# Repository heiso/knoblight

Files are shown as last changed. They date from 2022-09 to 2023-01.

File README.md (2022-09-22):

# KnobLight

Knoblight is a little IoT light knob acting as a dimmer for some homeassistant lights.
Once it's powered, it will connect to a wifi network and discuss with [Home Assistant (https://www.home-assistant.io)](https://www.home-assistant.io/) through [MQTT (https://www.home-assistant.io/integrations/mqtt)](https://www.home-assistant.io/integrations/mqtt/).

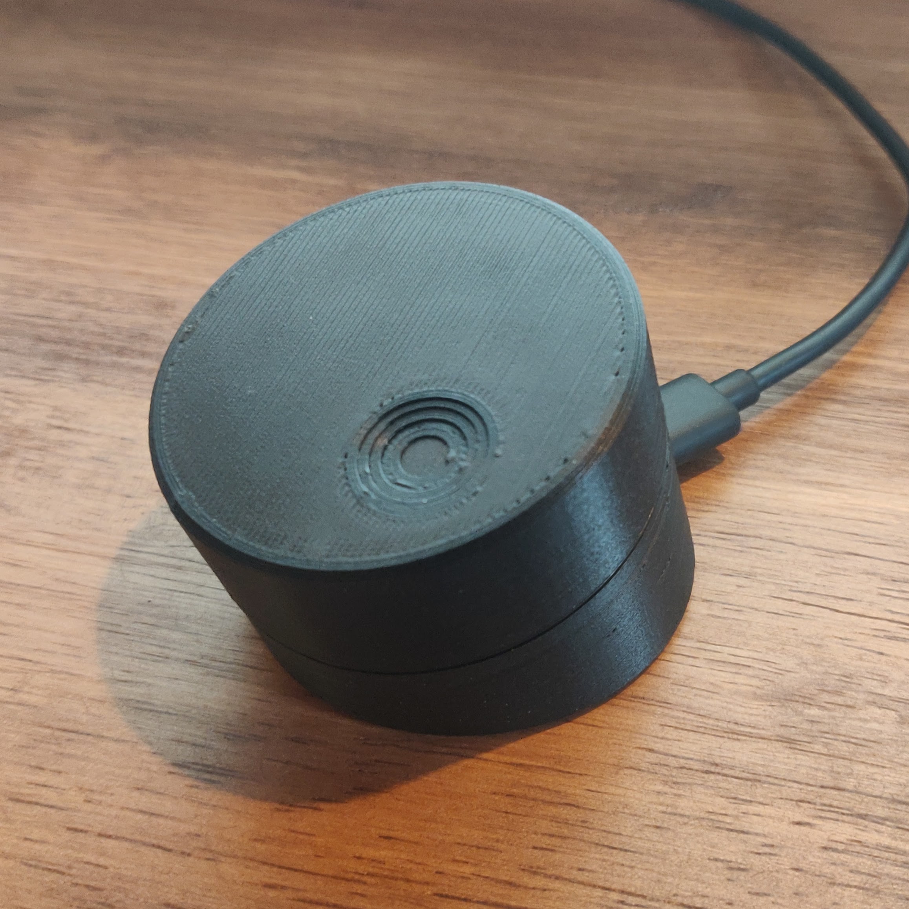
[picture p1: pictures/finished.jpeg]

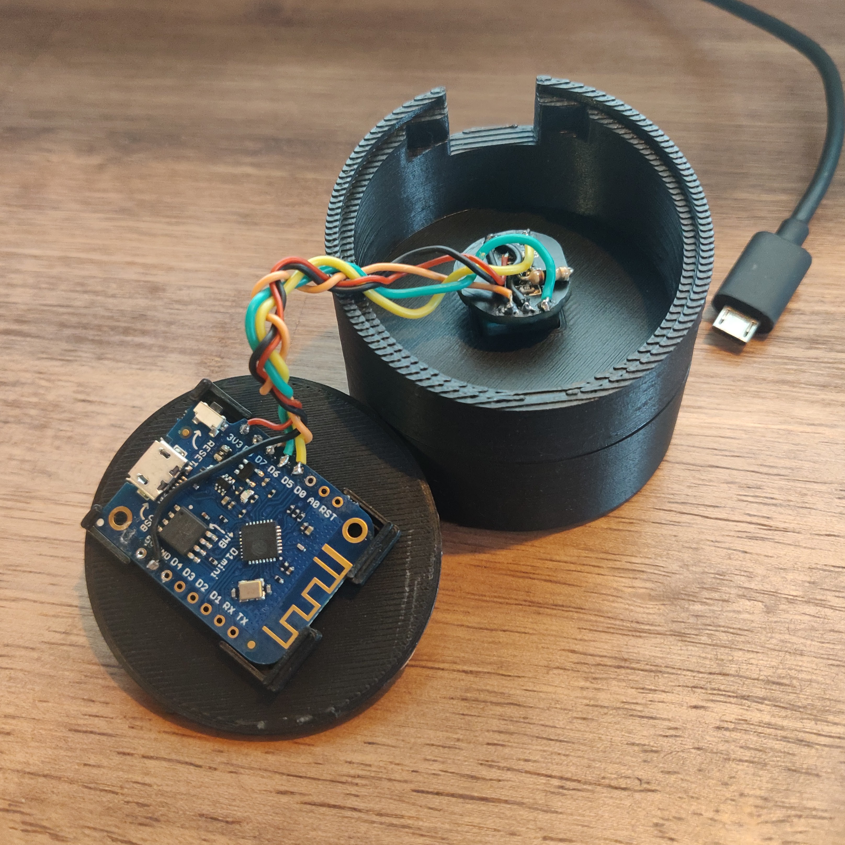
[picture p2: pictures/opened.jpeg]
  

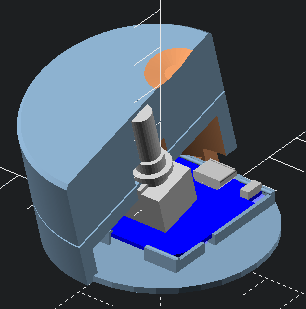
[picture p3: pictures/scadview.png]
scadview


## Scad design

You'll need to clone this openscad [library (https://github.com/heiso/openscad-bits)](https://github.com/heiso/openscad-bits) in your openscad libraries folder (probably `~/Documents/OpenSCAD/libraries/` on mac).

## Arduino code

You should copy `src/secrets.tpl.h` as `src/secrets.h` and set your values before trying to flash to your esp8266

## HA automation example

Given we want to control lights in the area_id **room**

```yaml
- id: 'knoblight_dimmer'
  alias: Knoblight - dimmer
  description: 'Set brightness accordingly to knoblight turns'
  trigger:
  - platform: mqtt
    topic: knoblight/brightness/set
  condition: []
  action:
  - service: light.turn_on
    data_template:
      transition: 1
      brightness: '{{ trigger.payload_json }}'
    target:
      area_id: room
  mode: queued
  max: 5

- id: 'knoblight_btn'
  alias: Knoblight - btn
  description: 'Toggle lights on knoblight btn pressed'
  trigger:
  - platform: mqtt
    topic: knoblight/btn
  condition: []
  action:
  - service: light.toggle
    data: {}
    target:
      area_id: room
  mode: single

- id: 'knoblight_sync'
  alias: Knoblight - sync
  description: 'Periodically send the light brightness to the knob so it can stay up to date'
  trigger:
  - platform: time_pattern
    seconds: /10
  condition: []
  action:
  - service: mqtt.publish
    data:
      topic: knoblight/brightness
      payload_template: '{{ state_attr(''light.room'', ''brightness'') }}'
  mode: single
```

## BOM (Bill Of Materials)

1 KY_040_encoder  
1 Wemos D1 mini (esp8266)

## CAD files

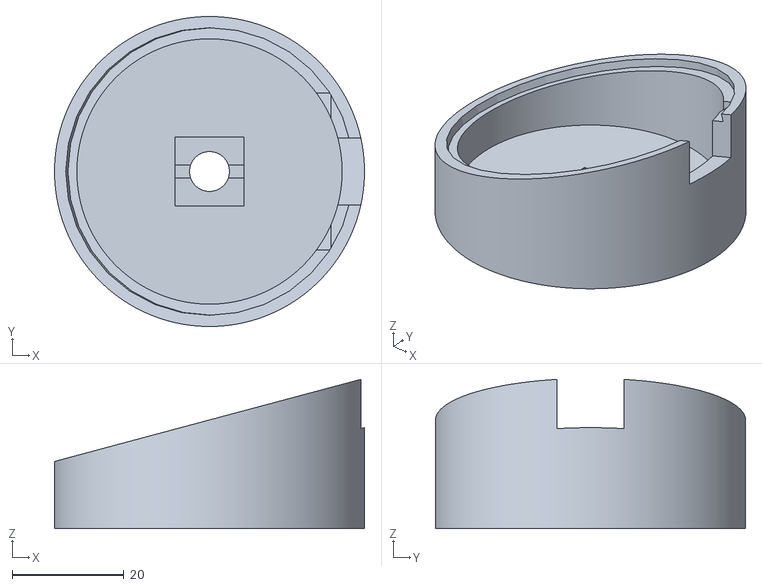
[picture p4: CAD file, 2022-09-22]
stl/base.stl
55.4 x 55.4 x 26.7

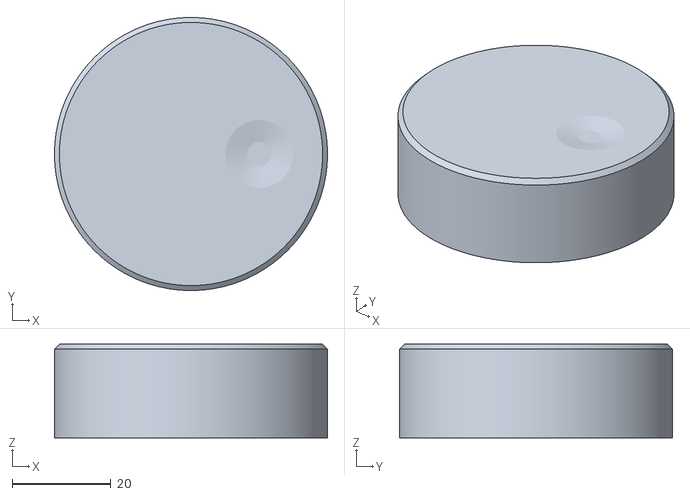
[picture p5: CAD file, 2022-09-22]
stl/knob.stl
55.4 x 55.4 x 19.0

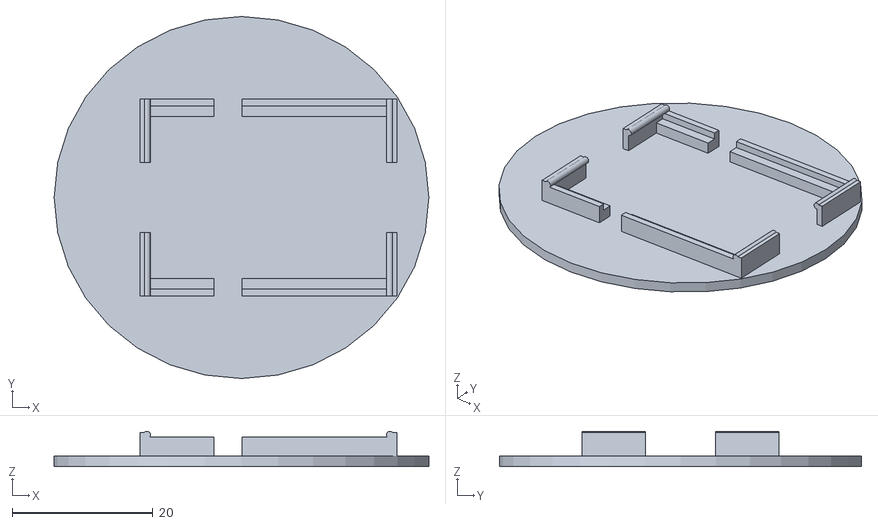
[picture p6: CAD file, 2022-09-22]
stl/bottom-plate.stl
53.2 x 51.4 x 5.03

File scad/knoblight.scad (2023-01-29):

include <openscad-bits/lib.scad>
use <openscad-bits/lib.scad>

$fn = 32;

knob_chamfer = 1;
knob_radius = 55.4 / 2;
knob_height = 19;
knob_angle = 15;
knob_rotation = [ 0, -knob_angle, 0 ];
knob_rotation_inversed = [ 0, knob_angle, 0 ];

base_height = 12;

bottom_plate_thickness = 1.5;

body_top_thickness = 2.5;

module wemos_d1_mini_esp8266_origin()
{
    translate([ 23, 0, bottom_plate_thickness ]) rotate([ 0, 0, 90 ]) children();
}

module rotary_encoder_origin()
{
    knob_origin() translate([ 0, 0, -body_top_thickness ]) children();
}

module knob()
{
    difference()
    {
        knob_origin() difference()
        {
            union()
            {
                $fn = 360;
                translate([ 0, 0, knob_height - knob_chamfer ]) hull()
                {
                    linear_extrude(height = thin) circle(r = knob_radius);
                    translate([ 0, 0, knob_chamfer ]) linear_extrude(height = thin) offset(delta = -knob_chamfer)
                        circle(r = knob_radius);
                }

                cylinder(h = knob_height - knob_chamfer, r = knob_radius);
            }

            translate([ knob_radius / 2, 0, knob_height + 50 / 2 - 1 ]) sphere(r = 50 / 2);
        }
        rotary_encoder_origin() rotary_encoder(body_top_thickness, cutout = true);
    }
}

module knob_origin()
{
    base_origin() translate([ 0, 0, base_height + 0.5 ]) children();
}

module base()
{
    difference()
    {
        clip(zmin = 0) base_origin() translate([ 0, 0, -tan(knob_angle) * knob_radius * 2 ]) difference()
        {
            $fn = 360;
            cylinder(h = base_height + (tan(knob_angle) * knob_radius * 2), r = knob_radius);
            cylinder(h = base_height + (tan(knob_angle) * knob_radius * 2) - 4, r = knob_radius - 4);
        }

        rotary_encoder_origin() rotary_encoder(body_top_thickness, cutout = true);
        translate([ -4, 0, 0 ]) wemos_d1_mini_esp8266_origin() cube([ wemos_d1_mini_esp8266_width + 2, 10, 8 ], true);
        translate([ knob_radius, 0, 0 ]) cube([ 10, 12, 17 ], true);
        bottom_plate();
    }
}

module base_origin()
{
    translate([ 0, 0, sin(knob_angle) * knob_radius ]) rotate(knob_rotation) children();
}

module bottom_plate()
{
    linear_extrude(bottom_plate_thickness)
    {
        projection() clip(zmax = thin) clip(zmin = 0) base_origin()
            translate([ 0, 0, -tan(knob_angle) * knob_radius * 2 ])
                cylinder(h = base_height + (tan(knob_angle) * knob_radius * 2) - 4, r = knob_radius - 2);

        projection() wemos_d1_mini_esp8266_origin() wemos_d1_mini_esp8266_supports();
    }

    wemos_d1_mini_esp8266_origin() wemos_d1_mini_esp8266_supports();
}

if ($preview)
{
    clip(ymin = 0) // uncomment if you want to see the inside
    {
        knob();
        base();
    }
    render() bottom_plate();

    rotary_encoder_origin() rotary_encoder(body_top_thickness);
    wemos_d1_mini_esp8266_origin() wemos_d1_mini_esp8266();
}
else
{
    translate([ knob_radius * 2 + 10, 0, -19.42 ]) rotate(knob_rotation_inversed) knob();
    translate([ 0, 0, 18.95 ]) rotate([ 180, 0, 0 ]) rotate(knob_rotation_inversed) base();
    translate([ 0, knob_radius * 2 + 10, 0 ]) bottom_plate();
}

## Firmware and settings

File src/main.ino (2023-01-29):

#include "pin_config.h";
#include "secrets.h";
#include <ESP8266WiFi.h>
#include <MQTT.h>
#include <MQTTClient.h>

// 00 10 [11] 01
enum ENCODER_STATE {
  IDLE, // 11

  CW_1, // 01
  CW_2, // 00
  CW_3, // 10,

  CCW_1, // 10
  CCW_2, // 00
  CCW_3, // 01
};
static enum ENCODER_STATE encoder_state = IDLE;
unsigned long last_sw_trigger_time;
unsigned long last_encoder_trigger_time;
unsigned long last_publish_time;
const int btn_debounce_delay = 250;
const int publish_debounce_delay = 250;
int delta = 0;
int brightness = 0;
const int factor = 10;

const char ssid[] = WIFI_SSID;
const char pass[] = WIFI_PASS;

WiFiClient net;
MQTTClient client;

void connect() {
  Serial.print("checking wifi...");
  while (WiFi.status() != WL_CONNECTED) {
    Serial.print(".");
    delay(1000);
  }

  Serial.print("\nconnecting...");
  while (!client.connect("knoblight", HA_USER, HA_PASS)) {
    Serial.print(".");
    delay(1000);
  }

  Serial.println("\nconnected!");

  client.subscribe("knoblight/brightness");
}

void cw_callback() {
  last_encoder_trigger_time = millis();
  Serial.println("CW");
  delta++;
}

void ccw_callback() {
  last_encoder_trigger_time = millis();
  Serial.println("CCW");
  delta--;
}

void sw_callback() {
  if ((millis() - last_sw_trigger_time) > btn_debounce_delay) {
    last_sw_trigger_time = millis();
    Serial.println("SW");
    client.publish("knoblight/btn", "1");
  }
}

void IRAM_ATTR encoder_ISR() {
  uint8 clk = digitalRead(PIN_ENC_CLK);
  uint8 dt = digitalRead(PIN_ENC_DT);

  switch (encoder_state) {
  case IDLE: {
    if (!clk && dt) {
      encoder_state = CW_1;
    } else if (clk && !dt) {
      encoder_state = CCW_1;
    }
    break;
  }

  case CW_1: {
    if (!clk && !dt) {
      encoder_state = CW_2;
    } else if (clk && dt) {
      encoder_state = IDLE;
    }
    break;
  }

  case CW_2: {
    if (clk && !dt) {
      encoder_state = CW_3;
    } else if (clk && dt) {
      encoder_state = IDLE;
    }
    break;
  }

  case CW_3: {
    if (clk && dt) {
      encoder_state = IDLE;
      cw_callback();
    }
    break;
  }

  case CCW_1: {
    if (!clk && !dt) {
      encoder_state = CCW_2;
    } else if (clk && dt) {
      encoder_state = IDLE;
    }
    break;
  }

  case CCW_2: {
    if (!clk && dt) {
      encoder_state = CCW_3;
    } else if (clk && dt) {
      encoder_state = IDLE;
    }
    break;
  }

  case CCW_3: {
    if (clk && dt) {
      encoder_state = IDLE;
      ccw_callback();
    }
    break;
  }
  }
}

void IRAM_ATTR button_ISR() {
  sw_callback();
}

void messageReceived(String &topic, String &payload) {
  Serial.println("incoming: " + topic + " - " + payload);

  if (topic == "knoblight/brightness") {
    brightness = atoi(payload.c_str());
  }
}

void publish() {
  brightness = brightness + delta * factor;
  if (brightness > 255) {
    brightness = 255;
  } else if (brightness < 0) {
    brightness = 0;
  }
  delta = 0;
  client.publish("knoblight/brightness/set", String(brightness));
  Serial.print("Sending brightness ");
  Serial.println(String(brightness));
}

void setup() {
  Serial.begin(115200);

  last_sw_trigger_time = millis();

  pinMode(PIN_ENC_CLK, INPUT_PULLUP);
  pinMode(PIN_ENC_DT, INPUT_PULLUP);
  pinMode(PIN_ENC_SW, INPUT_PULLUP);

  attachInterrupt(digitalPinToInterrupt(PIN_ENC_CLK), encoder_ISR, CHANGE);
  attachInterrupt(digitalPinToInterrupt(PIN_ENC_DT), encoder_ISR, CHANGE);
  attachInterrupt(digitalPinToInterrupt(PIN_ENC_SW), button_ISR, FALLING);

  WiFi.begin(ssid, pass);

  client.begin(BROKER_IP, net);

  client.onMessage(messageReceived);

  delay(1000);
  connect();
}

void loop() {
  client.loop();
  delay(10); // <- fixes some issues with WiFi stability

  if (!client.connected()) {
    connect();
  }

  if (delta != 0 && millis() - last_encoder_trigger_time > publish_debounce_delay) {
    publish();
  }
}

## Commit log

2022-09-22 🎉 First commit
    [knoblight.scad]
2022-09-22 📝 Add readme and stls
    [base.stl, bottom-plate.stl, knob.stl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]
2022-09-22 📝 Add pictures
2023-01-29 ♻️ Improve stuff
    [knoblight.scad]
